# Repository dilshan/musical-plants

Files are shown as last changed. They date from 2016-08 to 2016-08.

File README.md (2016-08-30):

# CoCA Emerge + Tech - Musical plants project

[CoCA](http://www.cocaartists.com) "Emerge + Tech" - Musical plants is an electronics, software and plants base exhibit we initially developed for [Cinnamon Colomboscope](http://www.cinnamoncolomboscope.com/) 2016 exhibition. This installation will feature a touch sensitive sensor that will generate a soothing sound from each plant. By interacting with individual plants, the audience can create musical compositions.

Sensor unit of this project consists with 14 high sensitive, configurable voltage detectors and USB interface. In this sensor unit we use Samsung's KA2284 as amplifier, level detector, and PIC18F4550 8-bit MCU as data multiplexer and USB I/O controller. PC817 opto isolators are used to interface between analog front-end and digital data processor. In this design both analog and digital circuits are physically and electronically isolated to minimize the noises and interferences.

### Compiling source code

PC application of this project is developed by using [HIDAPI](https://github.com/signal11/hidapi) and [irrKlang](http://www.ambiera.com/irrklang) libraries. This application is designed to work with <I>Microsoft Windows</I> operating systems and we tested it on Windows 7 and Windows 10. 

PC application of this project is developed using <I>Microsoft Visual C++ 2015</I> edition. To compile the application <I>HIDAPI</I> and <I>irrKlang</I> source codes and libraries are need to copy into \frontend directory. 

PIC18F4550 firmware is developed using <I>MikroElektronika's mikroC PRO for PIC</I> compiler. Recommended MCU configuration register values for this firmware is listed in below:

* PLL prescaler : /5 (20 MHz)
* System clock postscaler : /2 (/1)
* USB clock : 96 MHz PLL /2
* Osciliator : HSPLL
* Fail safe clock monitor : OFF
* Internal external switching : OFF
* Power-up timer : OFF
* Brown-out reset : OFF
* Brown-out reset voltage : 2.0V
* USB voltage regulator : ON
* Watchdog timer : OFF
* Watchdog timer postscaler : 1:32768
* CCP2 multiplexed with : RC1
* PortB reset state : Digital
* Low power timer 1 osc : High power
* MCLR pin : Reset
* Stack overflow / underflow : ON
* In-circuit port : OFF
* Enhanced CPU : OFF
* Boot block : OPEN
* Code lock : OPEN
* Data EEPROM : OPEN
* Table write boot block : OPEN
* Table write code : OPEN
* Table read boot block : OPEN
* Table read code : OPEN

### Licenses

All the audio clips used in this project are produced by using xylophone and released under the terms of [Creative Commons Attribution-ShareAlike 4.0 International License](https://creativecommons.org/licenses/by-sa/4.0) (CC BY-SA 4.0).

This musical plants project is an open source hardware project and all the source codes and compiled binaries are released under the [MIT Licenses](https://opensource.org/licenses/MIT).

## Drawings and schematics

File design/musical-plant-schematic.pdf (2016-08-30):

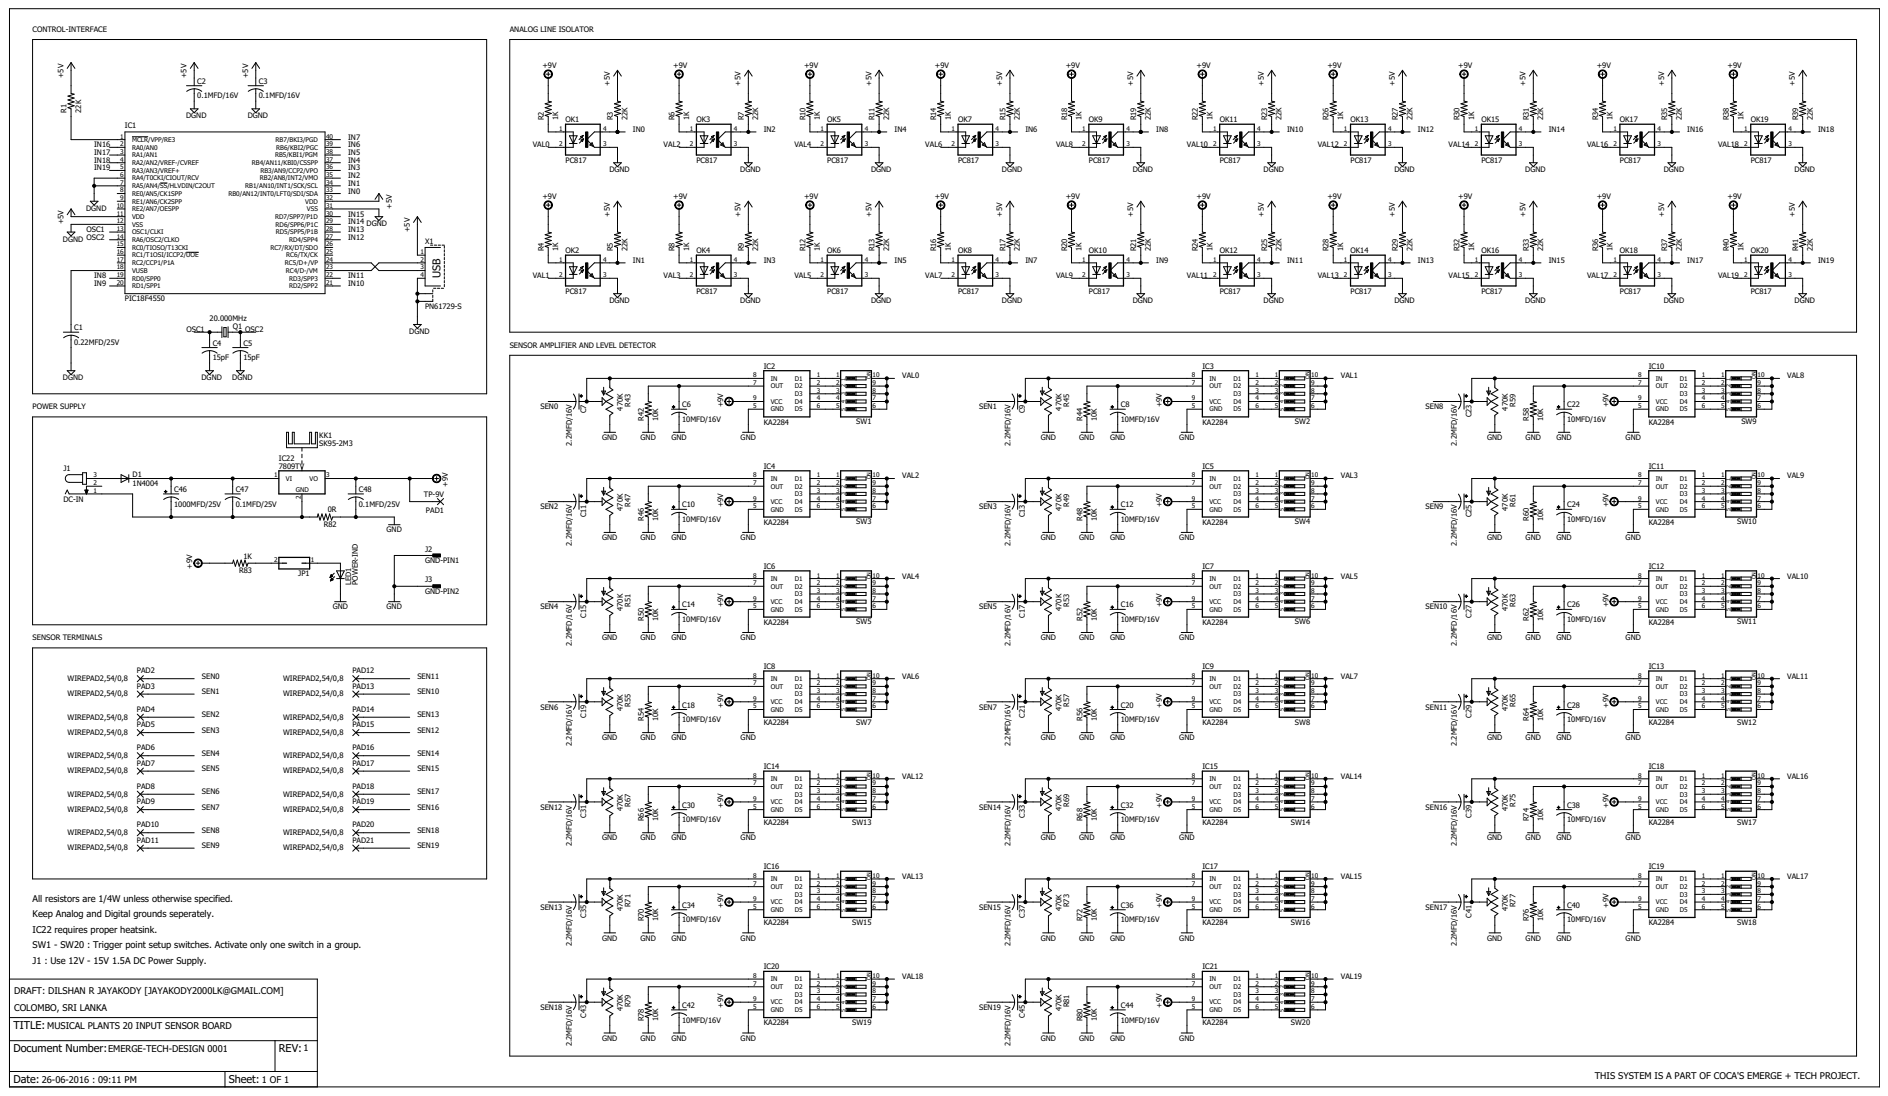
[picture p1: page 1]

SENSOR AMPLIFIER AND LEVEL DETECTOR

All resistors are 1/4W unless otherwise specified. Keep Analog and Digital grounds seperately. IC22 requires proper heatsink. SW1 - SW20 : Trigger point setup switches. Activate only one switch in a group. J1 : Use 12V - 15V 1.5A DC Power Supply.

DRAFT: DILSHAN R JAYAKODY [JAYAKODY2000LK@GMAIL.COM]

MUSICAL PLANTS 20 INPUT SENSOR BOARD

Document Number: EMERGE-TECH-DESIGN 0001 | REV: 1

Date: 26-06-2016 : 09:11 PM | Sheet: 1 OF 1

THIS SYSTEM IS A PART OF COCA'S EMERGE + TECH PROJECT.

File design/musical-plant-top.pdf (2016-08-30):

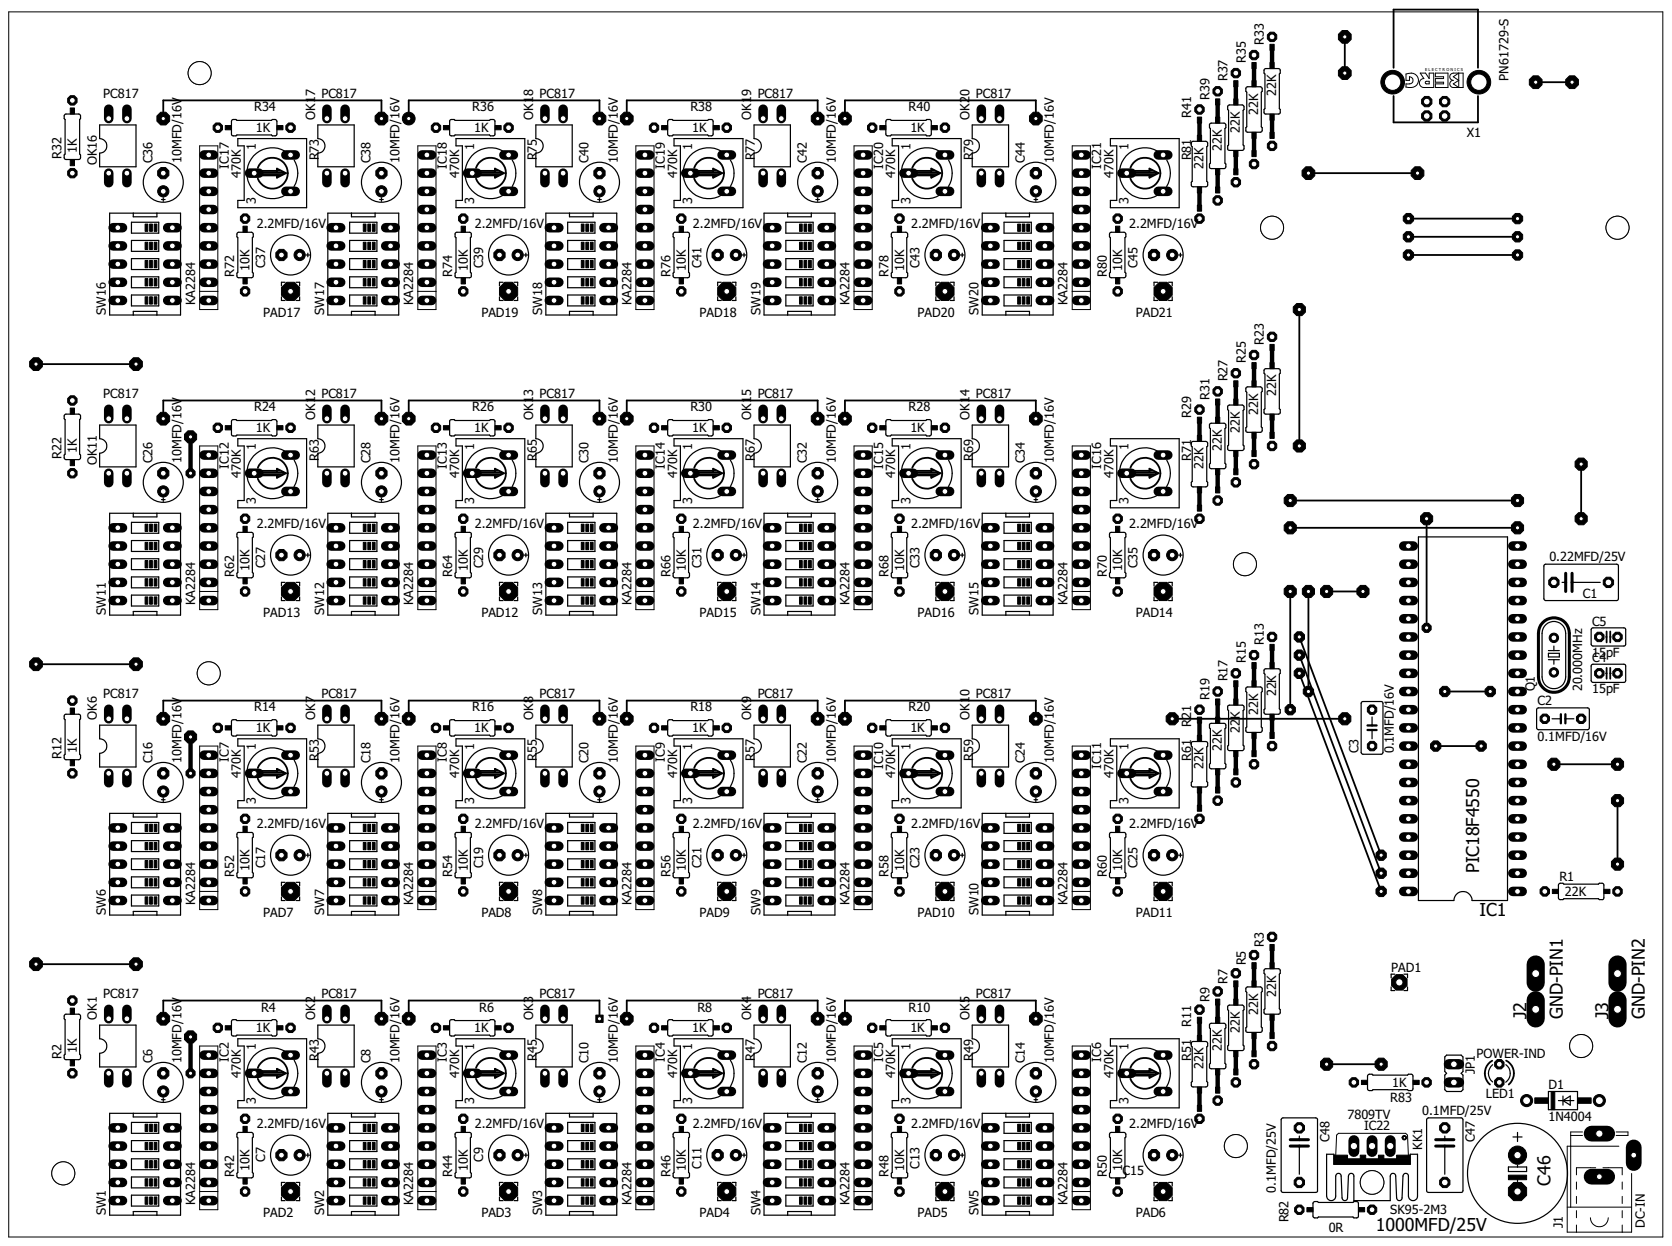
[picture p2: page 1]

1 3 1 3 1 3 1 3 1 3 1 3 1 3 1 3 1 3 1 3 1 3 1 3 1 3 1 3 1 3 1 3 1 3 1 3 1 3 1 3 E L E C T R O N I C S C1 C10 C11 C12 C13 C14 C15 C16 C17 C18 C19 C2 C20 C21 C22 C23 C24 C25 C26 C27 C28 C29 C3 C30 C31 C32 C33 C34 C35 C36 C37 C38 C39 C4 C40 C41 C42 C43 C44 C45 C46 C47 C48 C5 C6 C7 C8 C9 D1 IC1 IC10 IC11 IC12 IC13 IC14 IC15 IC16 IC17 IC18 IC19 IC2 IC20 IC21 IC22 IC3 IC4 IC5 IC6 IC7 IC8 IC9 J1 J2J3 JP1 KK1 LED1 OK1 OK10 OK11 OK12 OK13 OK14 OK15 OK16 OK17 OK18 OK19 OK2 OK20 OK3 OK4 OK5 OK6 OK7 OK8 OK9 PAD1 Q1 R1 R10 R11 R12 R13 R14 R15 R16 R17 R18 R19 R2 R20 R21 R22 R23 R24 R25 R26 R27 R28 R29 R3 R30 R31 R32 R33 R34 R35 R36 R37 R38 R39 R4 R40 R41 R42 R43 R44 R45 R46 R47 R48 R49 R5 R50 R51 R52 R53 R54 R55 R56 R57 R58 R59 R6 R60 R61 R62 R63 R64 R65 R66 R67 R68 R69 R7 R70 R71 R72 R73 R74 R75 R76 R77 R78 R79 R8 R80 R81 R82 R83 R9 SW1 SW10 SW11 SW12 SW13 SW14 SW15 SW16 SW17 SW18 SW19 SW2 SW20 SW3 SW4 SW5 SW6 SW7 SW8 SW9 X1 PAD2 PAD3 PAD4 PAD5 PAD6 PAD7 PAD8 PAD9 PAD10 PAD11 PAD13 PAD12 PAD15 PAD16 PAD14 PAD17 PAD19 PAD18 PAD20 PAD21 0.22MFD/25V 10MFD/16V 2.2MFD/16V 10MFD/16V 2.2MFD/16V 10MFD/16V 2.2MFD/16V 10MFD/16V 2.2MFD/16V 10MFD/16V 2.2MFD/16V 0.1MFD/16V 10MFD/16V 2.2MFD/16V 10MFD/16V 2.2MFD/16V 10MFD/16V 2.2MFD/16V 10MFD/16V 2.2MFD/16V 10MFD/16V 2.2MFD/16V 0.1MFD/16V 10MFD/16V 2.2MFD/16V 10MFD/16V 2.2MFD/16V 10MFD/16V 2.2MFD/16V 10MFD/16V 2.2MFD/16V 10MFD/16V 2.2MFD/16V 15pF 10MFD/16V 2.2MFD/16V 10MFD/16V 2.2MFD/16V 10MFD/16V 2.2MFD/16V 1000MFD/25V 0.1MFD/25V 0.1MFD/25V 15pF 10MFD/16V 2.2MFD/16V 10MFD/16V 2.2MFD/16V 1N4004 PIC18F4550 KA2284 KA2284 KA2284 KA2284 KA2284 KA2284 KA2284 KA2284 KA2284 KA2284 KA2284 KA2284 KA2284 7809TV KA2284 KA2284 KA2284 KA2284 KA2284 KA2284 KA2284 DC-IN GND-PIN1 GND-PIN2 SK95-2M3 POWER-IND PC817 PC817 PC817 PC817 PC817 PC817 PC817 PC817 PC817 PC817 PC817 PC817 PC817 PC817 PC817 PC817 PC817 PC817 PC817 PC817 20.000MHz 22K 1K 22K 1K 22K 1K 22K 1K 22K 1K 22K 1K 1K 22K 1K 22K 1K 22K 1K 22K 1K 22K 22K 1K 22K 1K 22K 1K 22K 1K 22K 1K 22K 1K 1K 22K 10K 470K 10K 470K 10K 470K 10K 470K 22K 10K 470K 10K 470K 10K 470K 10K 470K 10K 470K 1K 10K 470K 10K 470K 10K 470K 10K 470K 10K 470K 22K 10K 470K 10K 470K 10K 470K 10K 470K 10K 470K 1K 10K 470K 0R 1K 22K PN61729-S

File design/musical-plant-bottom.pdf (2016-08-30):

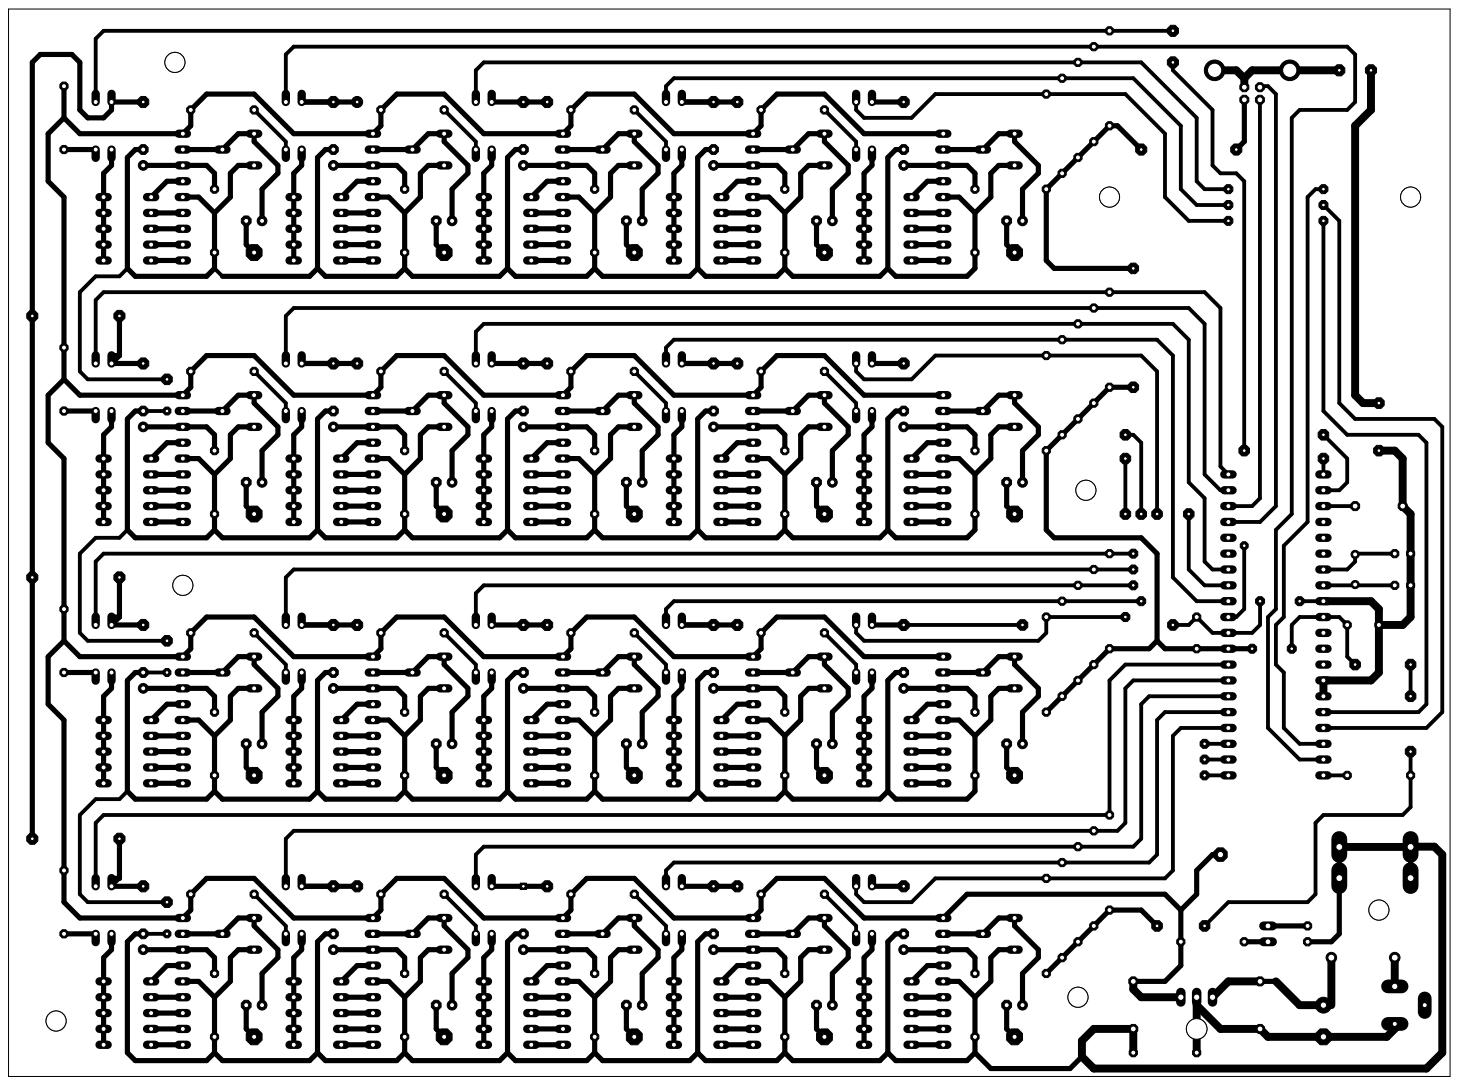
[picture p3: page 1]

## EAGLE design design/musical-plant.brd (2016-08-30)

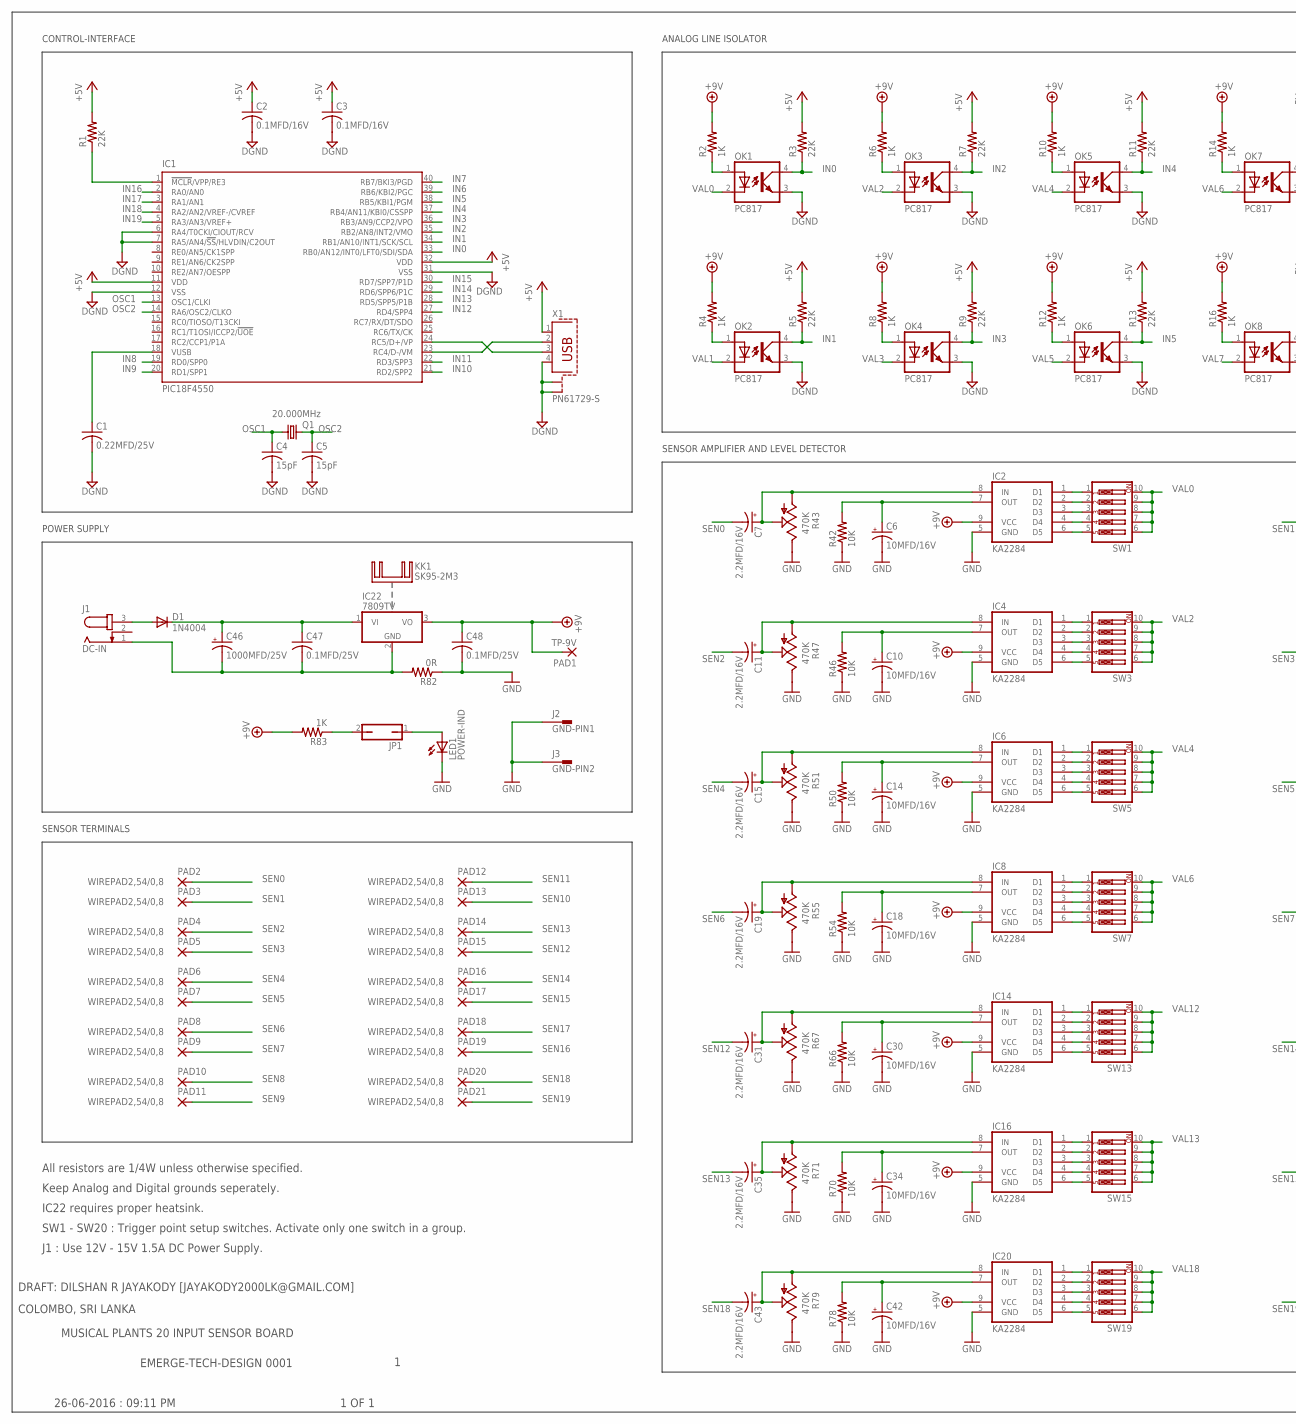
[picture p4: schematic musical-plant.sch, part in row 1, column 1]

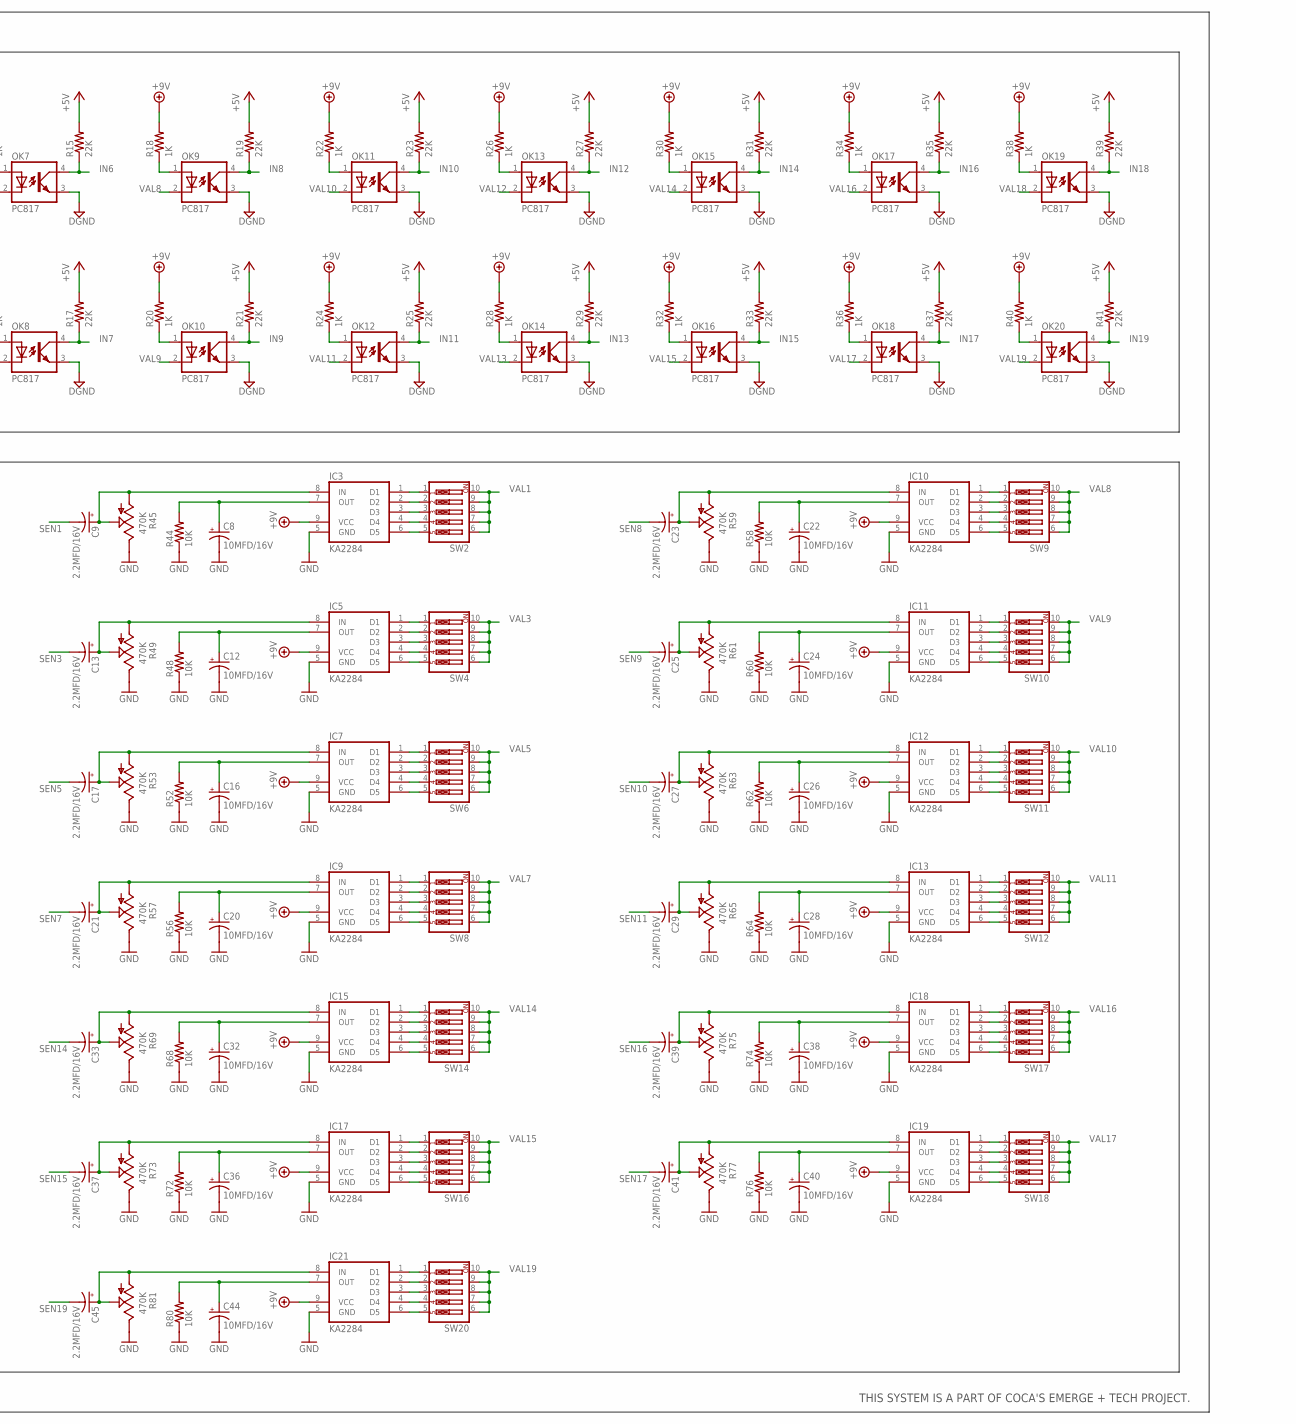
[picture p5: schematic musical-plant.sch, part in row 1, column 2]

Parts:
C1: 0.22MFD/25V; C075-052X106
C2, C3: 0.1MFD/16V; C050-030X075
C4, C5: 15pF; C025-025X050
C6, C8, C10, C12, C14, C16, C18, C20, C22, C24, C26, C28, C30, C32, C34, C36, C38, C40, C42, C44: 10MFD/16V; E2,5-6E
C7, C9, C11, C13, C15, C17, C19, C21, C23, C25, C27, C29, C31, C33, C35, C37, C39, C41, C43, C45: 2.2MFD/16V; E2,5-6E
C46: 1000MFD/25V; E5-13
C47, C48: 0.1MFD/25V; C075-052X106
D1: 1N4004; DO41-10
IC1: PIC18F4550; DIL40
IC2, IC3, IC4, IC5, IC6, IC7, IC8, IC9, IC10, IC11, IC12, IC13, IC14, IC15, IC16, IC17, IC18, IC19, IC20, IC21: KA2284; SIP-9
IC22: 7809TV; TO220V
J1: DC-IN; SPC4078
J2: GND-PIN1; F061.080
J3: GND-PIN2; F061.080
JP1: JP1Q; JP1
KK1: SK95-2M3
LED1: POWER-IND; LED3MM
OK1, OK2, OK3, OK4, OK5, OK6, OK7, OK8, OK9, OK10, OK11, OK12, OK13, OK14, OK15, OK16, OK17, OK18, OK19, OK20: PC817; DIL04
PAD1: TP-9V; 2,15/1,0
PAD2, PAD3, PAD4, PAD5, PAD6, PAD7, PAD8, PAD9, PAD10, PAD11, PAD12, PAD13, PAD14, PAD15, PAD16, PAD17, PAD18, PAD19, PAD20, PAD21: WIREPAD2,54/0,8; 2,54/0,8
Q1: 20.000MHz; HC49/S
R1: 22K; 0207/10
R2, R4, R6, R8, R10, R12, R14, R16, R18, R20, R22, R24, R26, R28, R30, R32, R34, R36, R38, R40, R83: 1K; 0207/10
R3, R5, R7, R9, R11, R13, R15, R17, R19, R21, R23, R25, R27, R29, R31, R33, R35, R37, R39, R41: 22K; 0207/15
R42, R44, R46, R48, R50, R52, R54, R56, R58, R60, R62, R64, R66, R68, R70, R72, R74, R76, R78, R80: 10K; 0207/10
R43, R45, R47, R49, R51, R53, R55, R57, R59, R61, R63, R65, R67, R69, R71, R73, R75, R77, R79, R81: 470K; RS3
R82: 0R; 0207/10
SW1, SW2, SW3, SW4, SW5, SW6, SW7, SW8, SW9, SW10, SW11, SW12, SW13, SW14, SW15, SW16, SW17, SW18, SW19, SW20: SW_DIP-5; EDG-05
X1: PN61729-S

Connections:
+5V: C2.1, C3.1, IC1.11 (VDD), IC1.32 (VDD), R1.2, R3.2, R5.2, R7.2, R9.2, R11.2, R13.2, R15.2, R17.2, R19.2, R21.2, R23.2, R25.2, R27.2, R29.2, R31.2, R33.2, R35.2, R37.2, R39.2, R41.2, X1.1
+9V: C48.1, IC2.9 (VCC), IC3.9 (VCC), IC4.9 (VCC), IC5.9 (VCC), IC6.9 (VCC), IC7.9 (VCC), IC8.9 (VCC), IC9.9 (VCC), IC10.9 (VCC), IC11.9 (VCC), IC12.9 (VCC), IC13.9 (VCC), IC14.9 (VCC), IC15.9 (VCC), IC16.9 (VCC), IC17.9 (VCC), IC18.9 (VCC), IC19.9 (VCC), IC20.9 (VCC), IC21.9 (VCC), IC22.3 (VO), PAD1.1, R2.2, R4.2, R6.2, R8.2, R10.2, R12.2, R14.2, R16.2, R18.2, R20.2, R22.2, R24.2, R26.2, R28.2, R30.2, R32.2, R34.2, R36.2, R38.2, R40.2, R83.2
D-MINUS: IC1.23 (RC4/D-/VM), X1.2
D-PLUS: IC1.24 (RC5/D+/VP), X1.3
DGND: C1.2, C2.2, C3.2, C4.2, C5.2, IC1.6 (RA4/T0CKI/CIOUT/RCV), IC1.7 (RA5/AN4/!SS!/HLVDIN/C2OUT), IC1.12 (VSS), IC1.31 (VSS), OK1.3 (EMIT), OK2.3 (EMIT), OK3.3 (EMIT), OK4.3 (EMIT), OK5.3 (EMIT), OK6.3 (EMIT), OK7.3 (EMIT), OK8.3 (EMIT), OK9.3 (EMIT), OK10.3 (EMIT), OK11.3 (EMIT), OK12.3 (EMIT), OK13.3 (EMIT), OK14.3 (EMIT), OK15.3 (EMIT), OK16.3 (EMIT), OK17.3 (EMIT), OK18.3 (EMIT), OK19.3 (EMIT), OK20.3 (EMIT), X1.4, X1.S1, X1.S2
GND: C6.-, C8.-, C10.-, C12.-, C14.-, C16.-, C18.-, C20.-, C22.-, C24.-, C26.-, C28.-, C30.-, C32.-, C34.-, C36.-, C38.-, C40.-, C42.-, C44.-, C48.2, IC2.5 (GND), IC3.5 (GND), IC4.5 (GND), IC5.5 (GND), IC6.5 (GND), IC7.5 (GND), IC8.5 (GND), IC9.5 (GND), IC10.5 (GND), IC11.5 (GND), IC12.5 (GND), IC13.5 (GND), IC14.5 (GND), IC15.5 (GND), IC16.5 (GND), IC17.5 (GND), IC18.5 (GND), IC19.5 (GND), IC20.5 (GND), IC21.5 (GND), J2.1A, J2.1B, J3.1A, J3.1B, LED1.K (C), R42.1, R43.E, R44.1, R45.E, R46.1, R47.E, R48.1, R49.E, R50.1, R51.E, R52.1, R53.E, R54.1, R55.E, R56.1, R57.E, R58.1, R59.E, R60.1, R61.E, R62.1, R63.E, R64.1, R65.E, R66.1, R67.E, R68.1, R69.E, R70.1, R71.E, R72.1, R73.E, R74.1, R75.E, R76.1, R77.E, R78.1, R79.E, R80.1, R81.E, R82.1
IN0: IC1.33 (RB0/AN12/INT0/LFT0/SDI/SDA), OK1.4 (COL), R3.1
IN1: IC1.34 (RB1/AN10/INT1/SCK/SCL), OK2.4 (COL), R5.1
IN2: IC1.35 (RB2/AN8/INT2/VMO), OK3.4 (COL), R7.1
IN3: IC1.36 (RB3/AN9/CCP2/VPO), OK4.4 (COL), R9.1
IN4: IC1.37 (RB4/AN11/KBI0/CSSPP), OK5.4 (COL), R11.1
IN5: IC1.38 (RB5/KBI1/PGM), OK6.4 (COL), R13.1
IN6: IC1.39 (RB6/KBI2/PGC), OK7.4 (COL), R15.1
IN7: IC1.40 (RB7/BKI3/PGD), OK8.4 (COL), R17.1
IN8: IC1.19 (RD0/SPP0), OK9.4 (COL), R19.1
IN9: IC1.20 (RD1/SPP1), OK10.4 (COL), R21.1
IN10: IC1.21 (RD2/SPP2), OK11.4 (COL), R23.1
IN11: IC1.22 (RD3/SPP3), OK12.4 (COL), R25.1
IN12: IC1.27 (RD4/SPP4), OK13.4 (COL), R27.1
IN13: IC1.28 (RD5/SPP5/P1B), OK14.4 (COL), R29.1
IN14: IC1.29 (RD6/SPP6/P1C), OK15.4 (COL), R31.1
IN15: IC1.30 (RD7/SPP7/P1D), OK16.4 (COL), R33.1
IN16: IC1.2 (RA0/AN0), OK17.4 (COL), R35.1
IN17: IC1.3 (RA1/AN1), OK18.4 (COL), R37.1
IN18: IC1.4 (RA2/AN2/VREF-/CVREF), OK19.4 (COL), R39.1
IN19: IC1.5 (RA3/AN3/VREF+), OK20.4 (COL), R41.1
MCLR: IC1.1 (!MCLR!/VPP/RE3), R1.1
unnamed: OK1.1 (A), R2.1
unnamed: OK2.1 (A), R4.1
unnamed: OK3.1 (A), R6.1
unnamed: OK4.1 (A), R8.1
unnamed: OK5.1 (A), R10.1
unnamed: OK6.1 (A), R12.1
unnamed: OK7.1 (A), R14.1
unnamed: OK8.1 (A), R16.1
unnamed: OK9.1 (A), R18.1
unnamed: OK10.1 (A), R20.1
unnamed: OK11.1 (A), R22.1
unnamed: OK12.1 (A), R24.1
unnamed: OK13.1 (A), R26.1
unnamed: OK14.1 (A), R28.1
unnamed: OK15.1 (A), R30.1
unnamed: OK16.1 (A), R32.1
unnamed: OK17.1 (A), R34.1
unnamed: OK18.1 (A), R36.1
unnamed: OK19.1 (A), R38.1
unnamed: OK20.1 (A), R40.1
unnamed: IC2.1 (D1), SW1.1
unnamed: IC2.2 (D2), SW1.2
unnamed: IC2.3 (D3), SW1.3
unnamed: IC2.4 (D4), SW1.4
unnamed: IC2.6 (D5), SW1.5
unnamed: C6.+, IC2.7 (OUT), R42.2
unnamed: C7.+, IC2.8 (IN), R43.A, R43.S
unnamed: IC3.1 (D1), SW2.1
unnamed: IC3.2 (D2), SW2.2
unnamed: IC3.3 (D3), SW2.3
unnamed: IC3.4 (D4), SW2.4
unnamed: IC3.6 (D5), SW2.5
unnamed: C8.+, IC3.7 (OUT), R44.2
unnamed: C9.+, IC3.8 (IN), R45.A, R45.S
unnamed: IC4.1 (D1), SW3.1
unnamed: IC4.2 (D2), SW3.2
unnamed: IC4.3 (D3), SW3.3
unnamed: IC4.4 (D4), SW3.4
unnamed: IC4.6 (D5), SW3.5
unnamed: C10.+, IC4.7 (OUT), R46.2
unnamed: C11.+, IC4.8 (IN), R47.A, R47.S
unnamed: IC5.1 (D1), SW4.1
unnamed: IC5.2 (D2), SW4.2
unnamed: IC5.3 (D3), SW4.3
unnamed: IC5.4 (D4), SW4.4
unnamed: IC5.6 (D5), SW4.5
unnamed: C12.+, IC5.7 (OUT), R48.2
unnamed: C13.+, IC5.8 (IN), R49.A, R49.S
unnamed: IC6.1 (D1), SW5.1
unnamed: IC6.2 (D2), SW5.2
unnamed: IC6.3 (D3), SW5.3
unnamed: IC6.4 (D4), SW5.4
unnamed: IC6.6 (D5), SW5.5
unnamed: C14.+, IC6.7 (OUT), R50.2
unnamed: C15.+, IC6.8 (IN), R51.A, R51.S
unnamed: IC7.1 (D1), SW6.1
unnamed: IC7.2 (D2), SW6.2
unnamed: IC7.3 (D3), SW6.3
unnamed: IC7.4 (D4), SW6.4
unnamed: IC7.6 (D5), SW6.5
unnamed: C16.+, IC7.7 (OUT), R52.2
unnamed: C17.+, IC7.8 (IN), R53.A, R53.S
unnamed: IC8.1 (D1), SW7.1
unnamed: IC8.2 (D2), SW7.2
unnamed: IC8.3 (D3), SW7.3
unnamed: IC8.4 (D4), SW7.4
unnamed: IC8.6 (D5), SW7.5
unnamed: C18.+, IC8.7 (OUT), R54.2
unnamed: C19.+, IC8.8 (IN), R55.A, R55.S
unnamed: IC9.1 (D1), SW8.1
unnamed: IC9.2 (D2), SW8.2
unnamed: IC9.3 (D3), SW8.3
unnamed: IC9.4 (D4), SW8.4
unnamed: IC9.6 (D5), SW8.5
unnamed: C20.+, IC9.7 (OUT), R56.2
unnamed: C21.+, IC9.8 (IN), R57.A, R57.S
unnamed: IC10.1 (D1), SW9.1
unnamed: IC10.2 (D2), SW9.2
unnamed: IC10.3 (D3), SW9.3
unnamed: IC10.4 (D4), SW9.4
unnamed: IC10.6 (D5), SW9.5
unnamed: C22.+, IC10.7 (OUT), R58.2
unnamed: C23.+, IC10.8 (IN), R59.A, R59.S
unnamed: IC11.1 (D1), SW10.1
unnamed: IC11.2 (D2), SW10.2
unnamed: IC11.3 (D3), SW10.3
unnamed: IC11.4 (D4), SW10.4
unnamed: IC11.6 (D5), SW10.5
unnamed: C24.+, IC11.7 (OUT), R60.2
unnamed: C25.+, IC11.8 (IN), R61.A, R61.S
unnamed: IC12.1 (D1), SW11.1
unnamed: IC12.2 (D2), SW11.2
unnamed: IC12.3 (D3), SW11.3
unnamed: IC12.4 (D4), SW11.4
unnamed: IC12.6 (D5), SW11.5
unnamed: C26.+, IC12.7 (OUT), R62.2
unnamed: C27.+, IC12.8 (IN), R63.A, R63.S
unnamed: IC13.1 (D1), SW12.1
unnamed: IC13.2 (D2), SW12.2
unnamed: IC13.3 (D3), SW12.3
unnamed: IC13.4 (D4), SW12.4
unnamed: IC13.6 (D5), SW12.5
unnamed: C28.+, IC13.7 (OUT), R64.2
unnamed: C29.+, IC13.8 (IN), R65.A, R65.S
unnamed: IC14.1 (D1), SW13.1
unnamed: IC14.2 (D2), SW13.2
unnamed: IC14.3 (D3), SW13.3
unnamed: IC14.4 (D4), SW13.4
unnamed: IC14.6 (D5), SW13.5
unnamed: C30.+, IC14.7 (OUT), R66.2
unnamed: C31.+, IC14.8 (IN), R67.A, R67.S
unnamed: IC15.1 (D1), SW14.1
unnamed: IC15.2 (D2), SW14.2
unnamed: IC15.3 (D3), SW14.3
unnamed: IC15.4 (D4), SW14.4
unnamed: IC15.6 (D5), SW14.5
unnamed: C32.+, IC15.7 (OUT), R68.2
unnamed: C33.+, IC15.8 (IN), R69.A, R69.S
unnamed: IC16.1 (D1), SW15.1
unnamed: IC16.2 (D2), SW15.2
unnamed: IC16.3 (D3), SW15.3
unnamed: IC16.4 (D4), SW15.4
unnamed: IC16.6 (D5), SW15.5
unnamed: C34.+, IC16.7 (OUT), R70.2
unnamed: C35.+, IC16.8 (IN), R71.A, R71.S
unnamed: IC17.1 (D1), SW16.1
unnamed: IC17.2 (D2), SW16.2
unnamed: IC17.3 (D3), SW16.3
unnamed: IC17.4 (D4), SW16.4
unnamed: IC17.6 (D5), SW16.5
unnamed: C36.+, IC17.7 (OUT), R72.2
unnamed: C37.+, IC17.8 (IN), R73.A, R73.S
unnamed: IC18.1 (D1), SW17.1
unnamed: IC18.2 (D2), SW17.2
unnamed: IC18.3 (D3), SW17.3
unnamed: IC18.4 (D4), SW17.4
unnamed: IC18.6 (D5), SW17.5
unnamed: C38.+, IC18.7 (OUT), R74.2
unnamed: C39.+, IC18.8 (IN), R75.A, R75.S
unnamed: IC19.1 (D1), SW18.1
unnamed: IC19.2 (D2), SW18.2
unnamed: IC19.3 (D3), SW18.3
unnamed: IC19.4 (D4), SW18.4
unnamed: IC19.6 (D5), SW18.5
unnamed: C40.+, IC19.7 (OUT), R76.2
unnamed: C41.+, IC19.8 (IN), R77.A, R77.S
unnamed: IC20.1 (D1), SW19.1
unnamed: IC20.2 (D2), SW19.2
unnamed: IC20.3 (D3), SW19.3
unnamed: IC20.4 (D4), SW19.4
unnamed: IC20.6 (D5), SW19.5
unnamed: C42.+, IC20.7 (OUT), R78.2
unnamed: C43.+, IC20.8 (IN), R79.A, R79.S
unnamed: IC21.1 (D1), SW20.1
unnamed: IC21.2 (D2), SW20.2
unnamed: IC21.3 (D3), SW20.3
unnamed: IC21.4 (D4), SW20.4
unnamed: IC21.6 (D5), SW20.5
unnamed: C44.+, IC21.7 (OUT), R80.2
unnamed: C45.+, IC21.8 (IN), R81.A, R81.S
unnamed: D1.A, J1.3
unnamed: C46.+, C47.1, D1.C, IC22.1 (VI)
unnamed: C46.-, C47.2, IC22.2 (GND), J1.1, R82.2
unnamed: JP1.1, LED1.A
unnamed: JP1.2, R83.1
OSC1: C4.1, IC1.13 (OSC1/CLKI), Q1.1
OSC2: C5.1, IC1.14 (RA6/OSC2/CLKO), Q1.2
SEN0: C7.-, PAD2.1
SEN1: C9.-, PAD3.1
SEN2: C11.-, PAD4.1
SEN3: C13.-, PAD5.1
SEN4: C15.-, PAD6.1
SEN5: C17.-, PAD7.1
SEN6: C19.-, PAD8.1
SEN7: C21.-, PAD9.1
SEN8: C23.-, PAD10.1
SEN9: C25.-, PAD11.1
SEN10: C27.-, PAD13.1
SEN11: C29.-, PAD12.1
SEN12: C31.-, PAD15.1
SEN13: C35.-, PAD14.1
SEN14: C33.-, PAD16.1
SEN15: C37.-, PAD17.1
SEN16: C39.-, PAD19.1
SEN17: C41.-, PAD18.1
SEN18: C43.-, PAD20.1
SEN19: C45.-, PAD21.1
VAL0: OK1.2 (C), SW1.6, SW1.7, SW1.8, SW1.9, SW1.10
VAL1: OK2.2 (C), SW2.6, SW2.7, SW2.8, SW2.9, SW2.10
VAL2: OK3.2 (C), SW3.6, SW3.7, SW3.8, SW3.9, SW3.10
VAL3: OK4.2 (C), SW4.6, SW4.7, SW4.8, SW4.9, SW4.10
VAL4: OK5.2 (C), SW5.6, SW5.7, SW5.8, SW5.9, SW5.10
VAL5: OK6.2 (C), SW6.6, SW6.7, SW6.8, SW6.9, SW6.10
VAL6: OK7.2 (C), SW7.6, SW7.7, SW7.8, SW7.9, SW7.10
VAL7: OK8.2 (C), SW8.6, SW8.7, SW8.8, SW8.9, SW8.10
VAL8: OK9.2 (C), SW9.6, SW9.7, SW9.8, SW9.9, SW9.10
VAL9: OK10.2 (C), SW10.6, SW10.7, SW10.8, SW10.9, SW10.10
VAL10: OK11.2 (C), SW11.6, SW11.7, SW11.8, SW11.9, SW11.10
VAL11: OK12.2 (C), SW12.6, SW12.7, SW12.8, SW12.9, SW12.10
VAL12: OK13.2 (C), SW13.6, SW13.7, SW13.8, SW13.9, SW13.10
VAL13: OK14.2 (C), SW15.6, SW15.7, SW15.8, SW15.9, SW15.10
VAL14: OK15.2 (C), SW14.6, SW14.7, SW14.8, SW14.9, SW14.10
VAL15: OK16.2 (C), SW16.6, SW16.7, SW16.8, SW16.9, SW16.10
VAL16: OK17.2 (C), SW17.6, SW17.7, SW17.8, SW17.9, SW17.10
VAL17: OK18.2 (C), SW18.6, SW18.7, SW18.8, SW18.9, SW18.10
VAL18: OK19.2 (C), SW19.6, SW19.7, SW19.8, SW19.9, SW19.10
VAL19: OK20.2 (C), SW20.6, SW20.7, SW20.8, SW20.9, SW20.10
VUSB: C1.1, IC1.18 (VUSB)

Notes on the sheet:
CONTROL-INTERFACE
ANALOG LINE ISOLATOR
SENSOR AMPLIFIER AND LEVEL DETECTOR
POWER SUPPLY
SENSOR TERMINALS
MUSICAL PLANTS 20 INPUT SENSOR BOARD
EMERGE-TECH-DESIGN 0001
1 OF 1
26-06-2016 : 09:11 PM
DRAFT: DILSHAN R JAYAKODY [JAYAKODY2000LK@GMAIL.COM]
COLOMBO, SRI LANKA
All resistors are 1/4W unless otherwise specified.
Keep Analog and Digital grounds seperately.
IC22 requires proper heatsink.
SW1 - SW20 : Trigger point setup switches. Activate only one switch in a group.
J1 : Use 12V - 15V 1.5A DC Power Supply.
THIS SYSTEM IS A PART OF COCA'S EMERGE + TECH PROJECT.

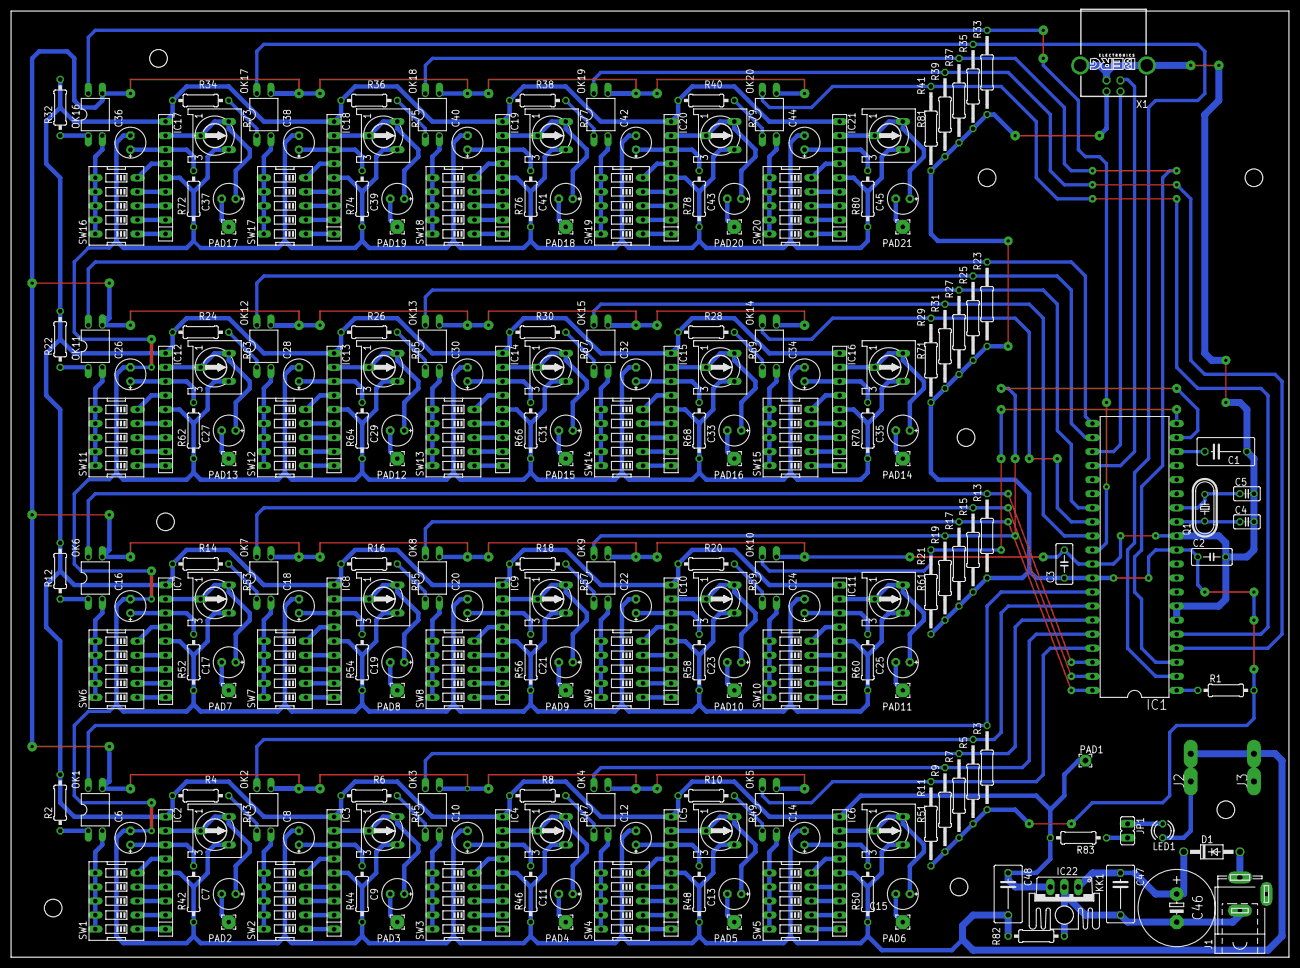
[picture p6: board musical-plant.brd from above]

Board: 2 copper layers, 231.1 x 171.1 mm, 223 parts (0 on the bottom side), 235 nets.

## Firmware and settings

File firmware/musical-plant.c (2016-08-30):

//****************************************************************************
// Musical Plants - PIC18F4550 Firmware (Version 1.0)
// Designed for CoCA Emerge + Tech project.
//
// Copyright (c) 2016 Dilshan R Jayakody [jayakody2000lk at gmail dot com].
//
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
#define DATA_PACKET_HEADER 0xC1

unsigned char readbuff[64] absolute 0x500;
unsigned char writebuff[64] absolute 0x540;

void interrupt()
{
   USB_Interrupt_Proc();
}

void main() 
{
  unsigned char arrayPos;
  unsigned char lastPortA = 0xFF, lastPortB = 0xFF, lastPortD = 0xFF;
  
  // Setup MCU register configuration.
  ADCON1 |= 0x0F;
  CMCON  |= 7;
  TRISA = 0xFF;
  TRISB = 0xFF;
  TRISD = 0xFF;
  PORTA = 0x00;
  PORTB = 0x00;
  PORTD = 0x00;
  
  // Enable USB HID.
  HID_Enable(&readbuff, &writebuff);
  
  // Setup HID data buffer.
  for(arrayPos = 0; arrayPos < 64; arrayPos++)
  {
    writebuff[arrayPos] = 0x00;
  }
  
  Delay_ms(100);

  // Service loop.
  while(1)
  {
    // Looking for any changes in input ports.
	if((PORTA != lastPortA) || (PORTB != lastPortB) || (PORTD != lastPortD))
    {
      lastPortA = PORTA;
      lastPortB = PORTB;
      lastPortD = PORTD;
      
      writebuff[0] = DATA_PACKET_HEADER;
      writebuff[1] = PORTA;
      writebuff[2] = PORTB;
      writebuff[3] = PORTD;
      
	  // Submit port status to host over allocated HID channel.
      while(!HID_Write(&writebuff, 64));
    }
    
    Delay_ms(100);
  }
}
